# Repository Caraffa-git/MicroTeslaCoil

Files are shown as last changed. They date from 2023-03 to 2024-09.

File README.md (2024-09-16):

# μTeslaCoil
Small PCB for push-pull tesla coil with 50V boost converter

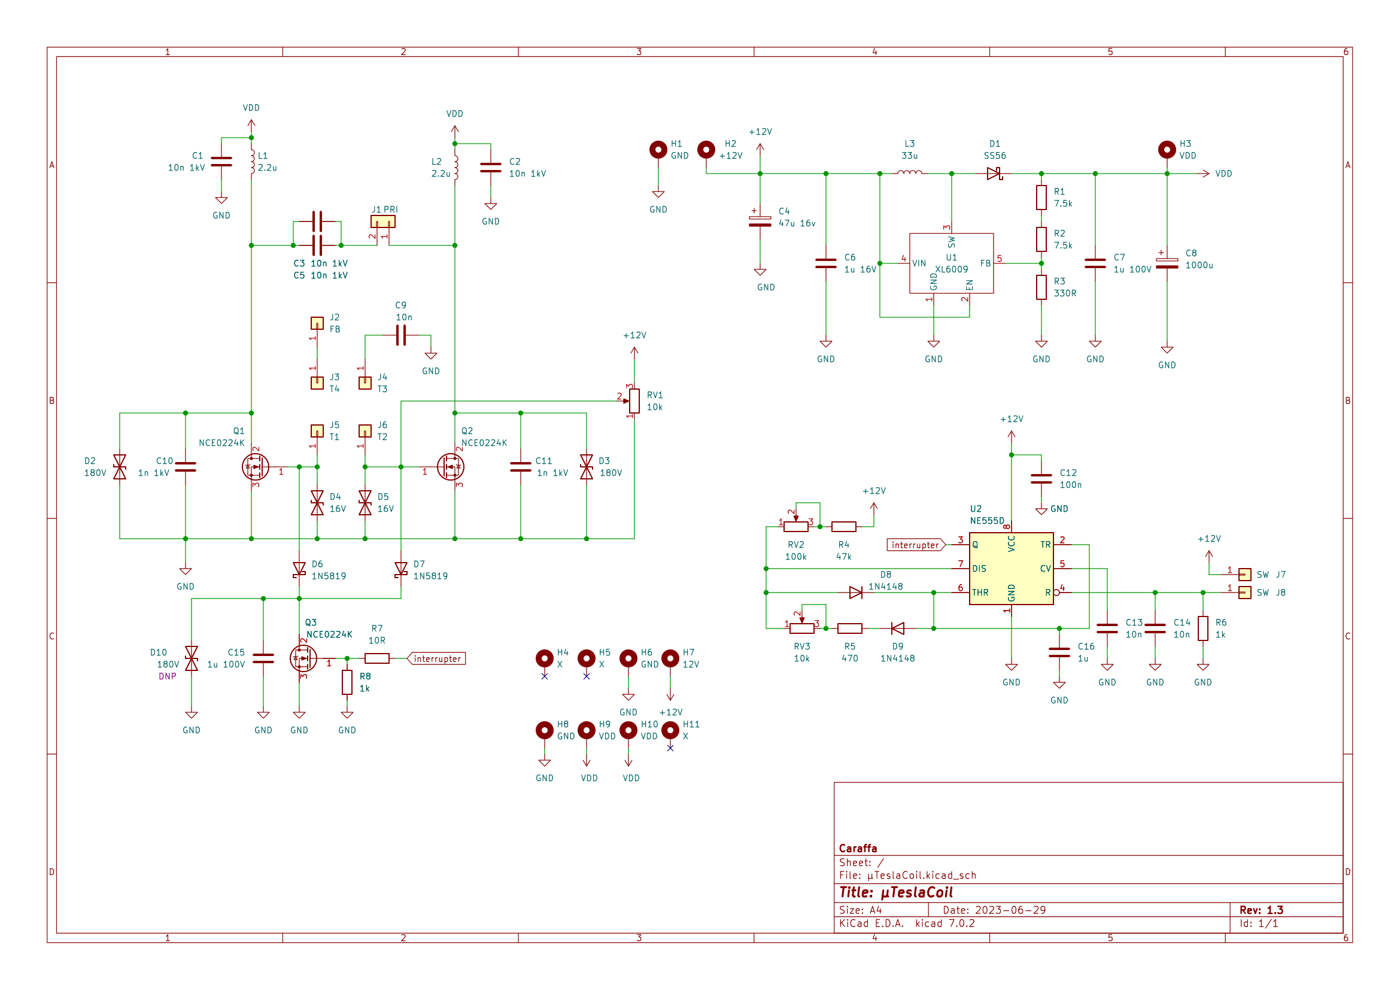
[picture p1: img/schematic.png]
schematic


## Notes and test results (<a href="https://github.com/Caraffa-git/MicroTeslaCoil/tree/b3fdc67581c9563461222aec662bbb1328c567a8">b3fdc67</a>)
The coil works, but aside from some not-so-wise design decisions that I changed in the current version, I encountered a few problems.
- At first the idea was to use a slayer-exciter sized secondary but as it turned out driving a coil with a frequency close to 5MHz can be challenging in terms of tuning. I ended up using a slightly larger secondary with a resonance frequency close to 500-600kHz.
- The lack of TVS diodes cost me some IGBTs so I added them in this version. As it turns out, reverse connection of the primary winding causes high voltage spikes and thus damage to the circuit.
- The voltage converter that I used has a limit of ~60V on the output, but there is some headroom so you can experiment with higher voltages. I think the circuit should be able to withstand about 80V on the input.

<!-- |   |   |   |
|---|---|---|
| ![Photo 2](./img/PIC_2.jpg) |![Photo 3](./img/PIC_3.jpg) | ![Photo 4](./img/PIC_4.jpg)| -->

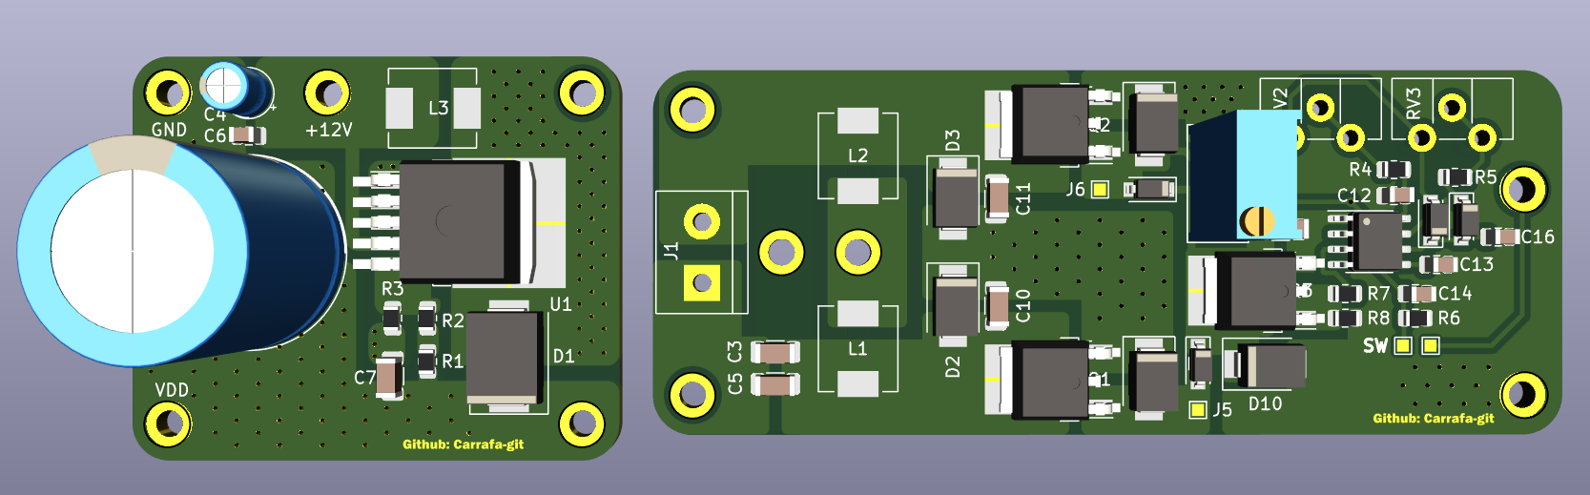
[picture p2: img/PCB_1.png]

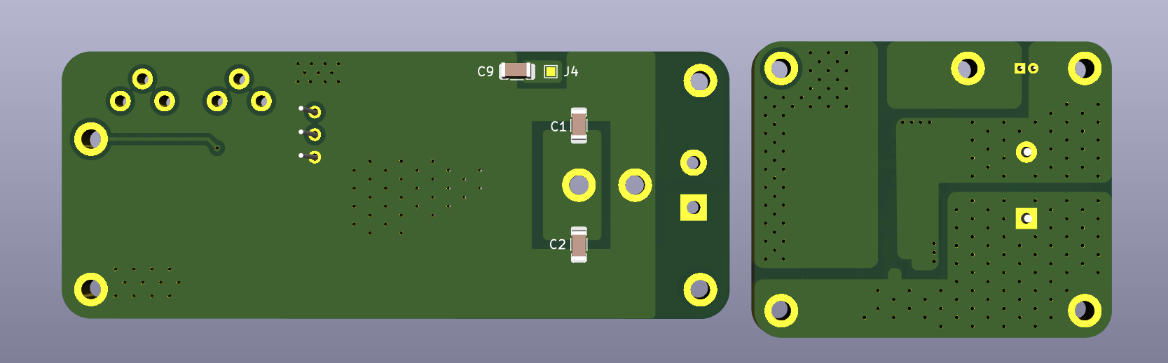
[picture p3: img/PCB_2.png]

<!-- ![base](./img/PIC_1.jpg) -->

## TODO
- Add Q3 gate protection
- Add U2 VCC regulation/protection 

## Links
https://www.youtube.com/watch?v=w9AY5RUtEMk   
https://tefatronix.g6.cz/display.php?page=sstc4&lang=en   
~~https://blog.naver.com/3happy3gong3/222702706706~~   
https://github.com/Caraffa-git/PCB-Art

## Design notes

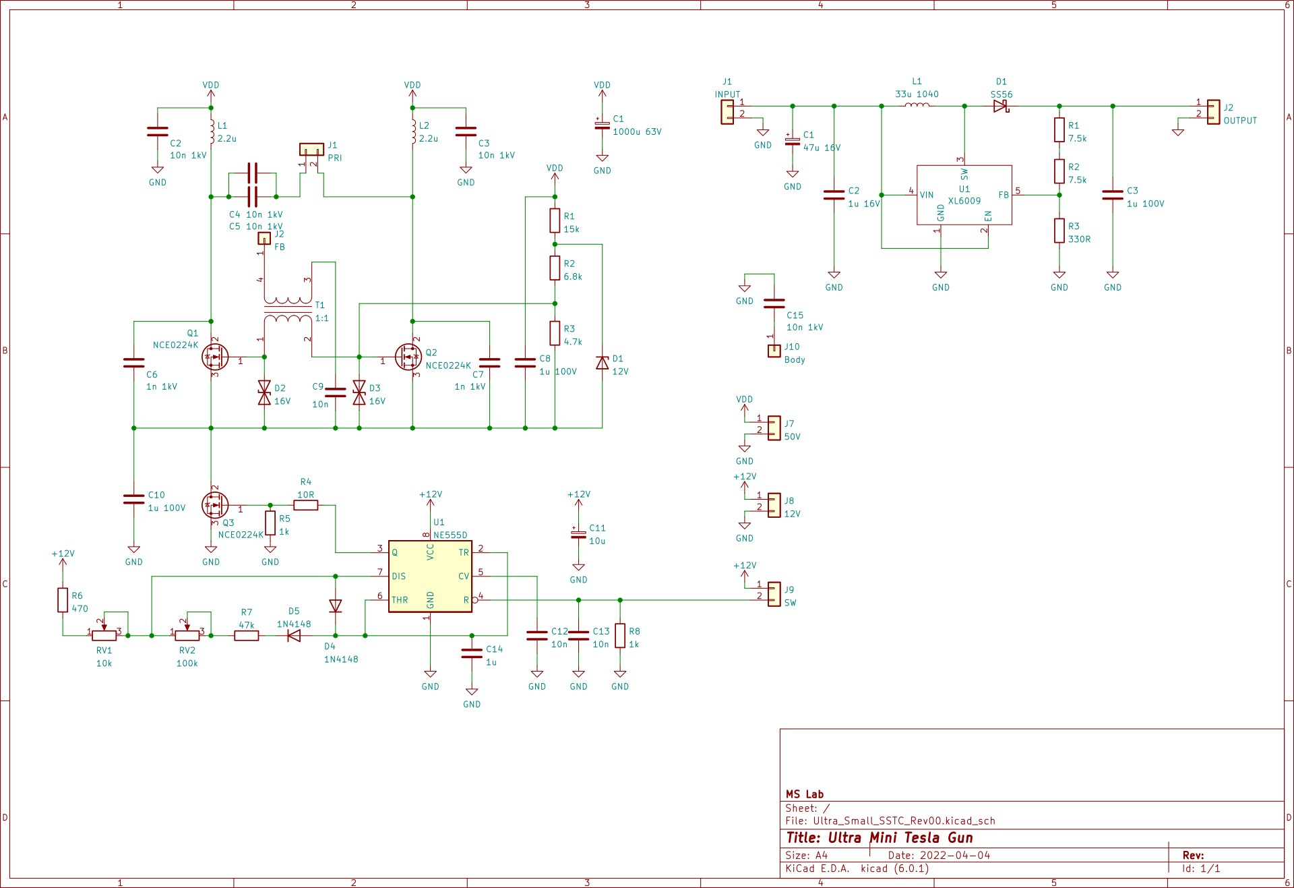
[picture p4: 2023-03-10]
img/original_schematic.png

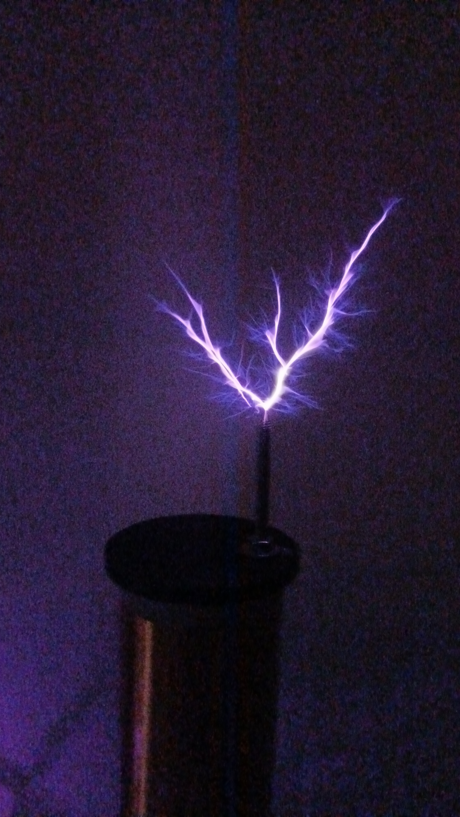
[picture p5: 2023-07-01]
img/PIC_3.jpg

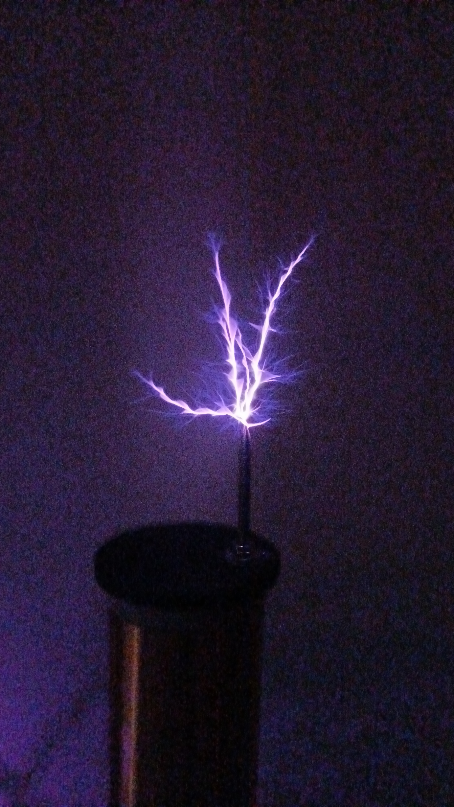
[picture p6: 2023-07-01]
img/PIC_4.jpg

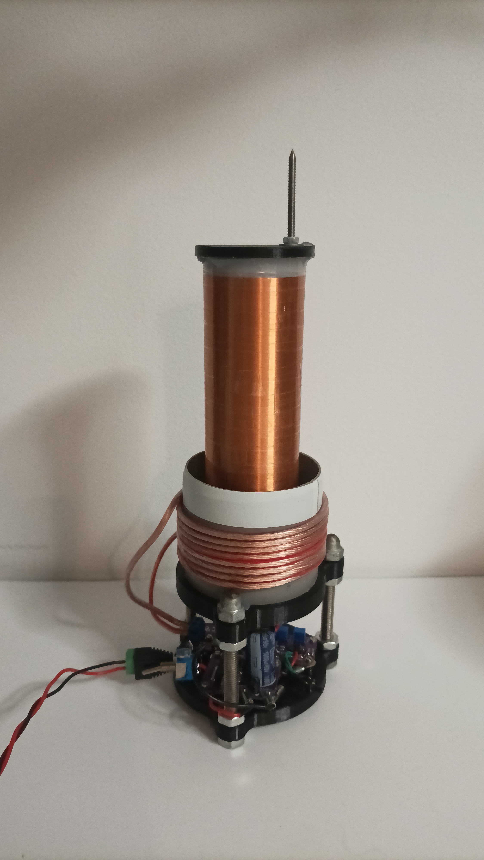
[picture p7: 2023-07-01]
img/PIC_2.jpg

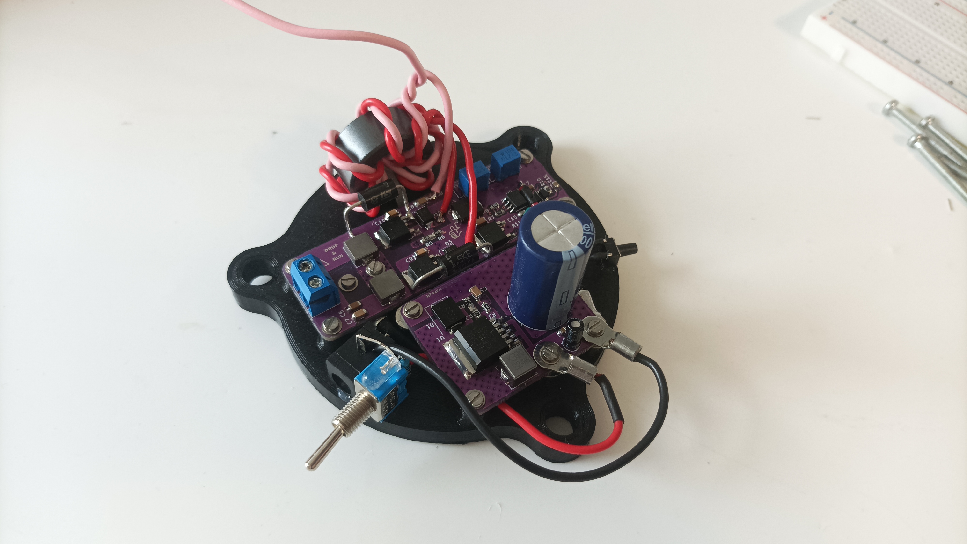
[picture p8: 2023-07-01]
img/PIC_1.jpg

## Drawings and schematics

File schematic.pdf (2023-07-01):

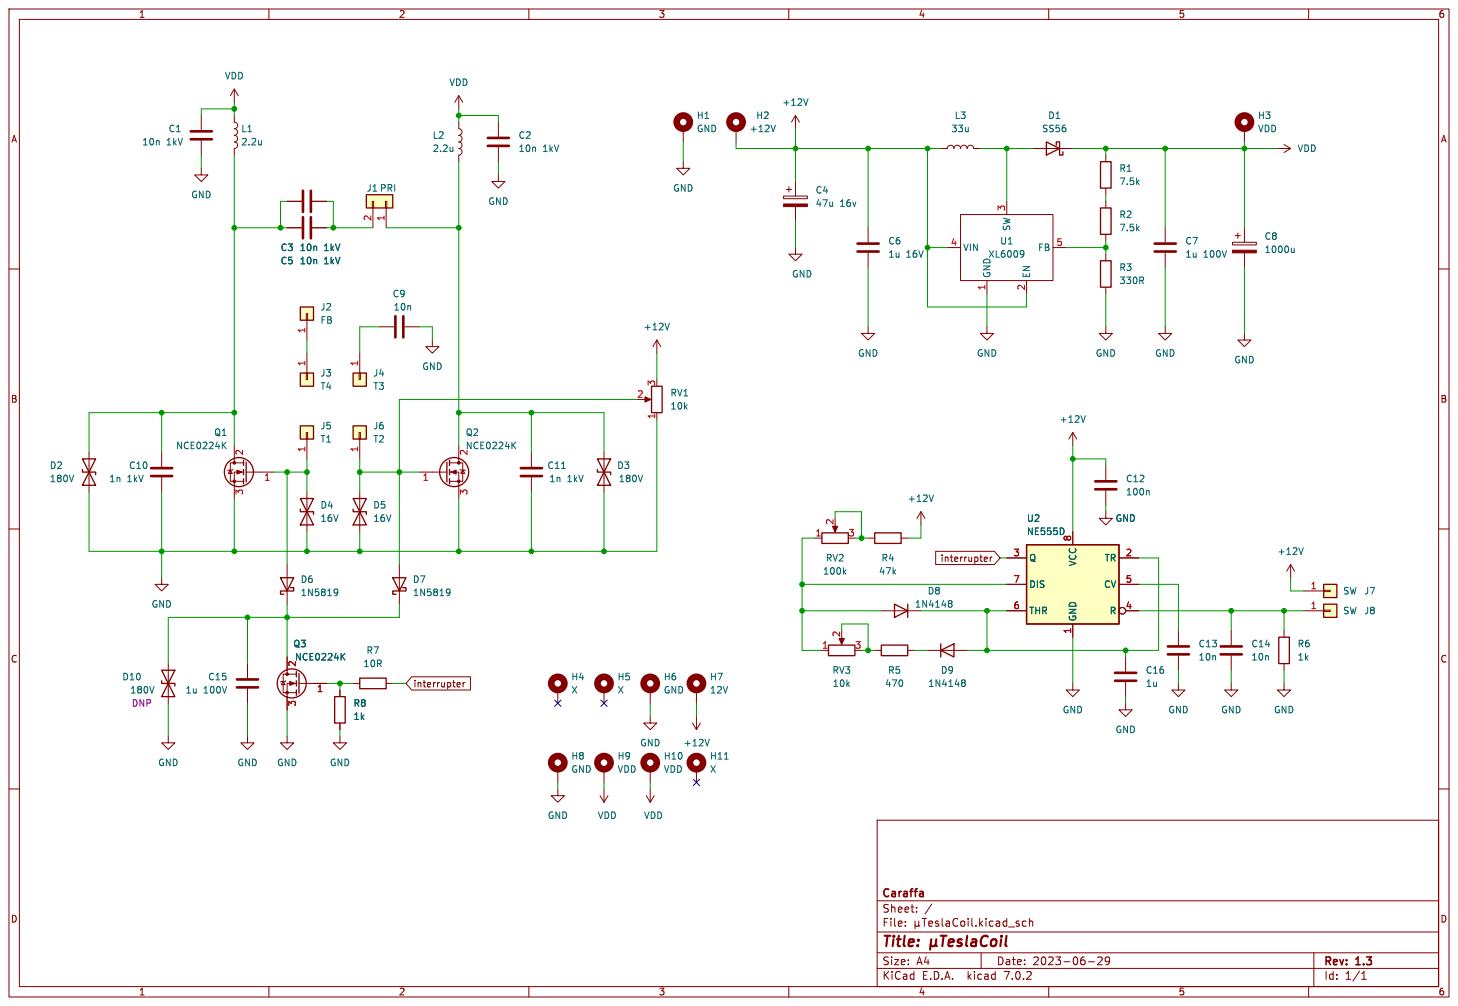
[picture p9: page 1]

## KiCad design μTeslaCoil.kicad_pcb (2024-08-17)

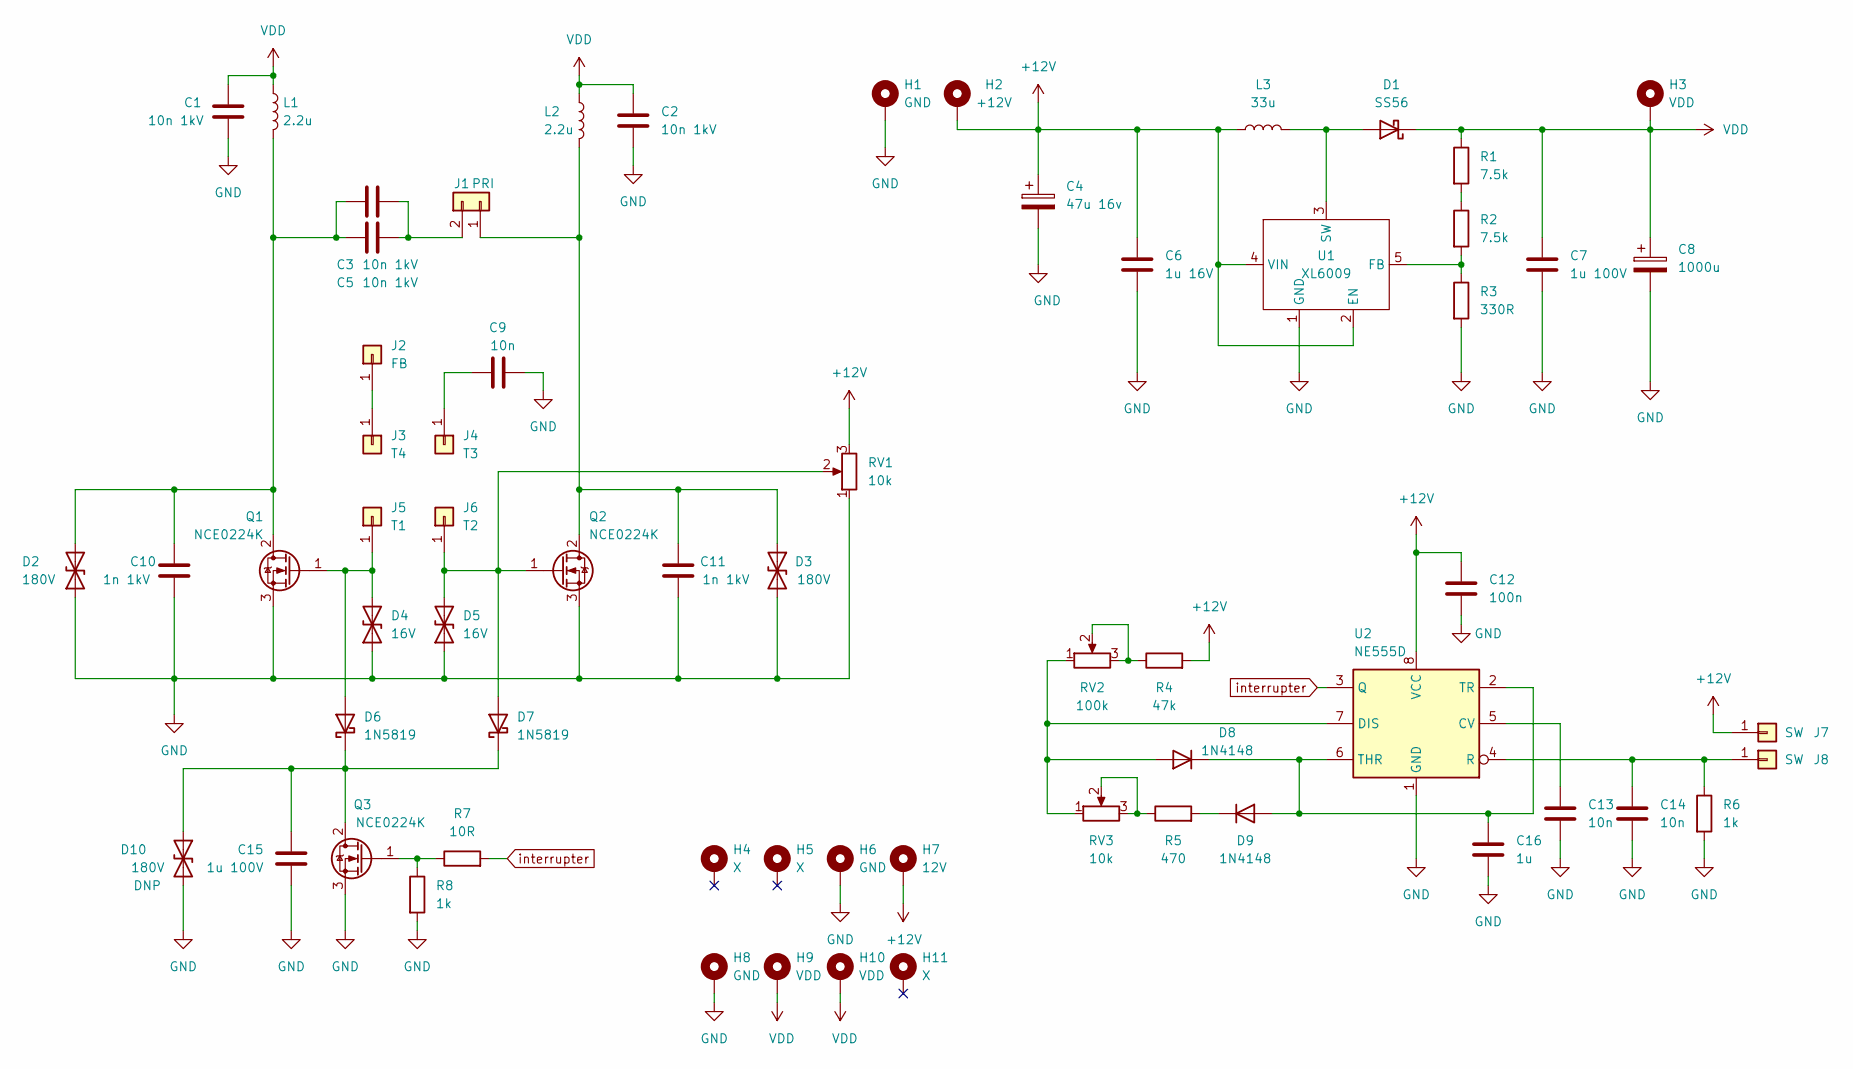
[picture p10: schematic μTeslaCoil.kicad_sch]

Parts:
C1, C2, C3, C5: 10n 1kV; C_1206_3216Metric
C4: 47u 16v; CP_Radial_D4.0mm_P1.50mm
C6: 1u 16V; C_0805_2012Metric
C7, C15: 1u 100V; C_1206_3216Metric
C8: 1000u; CP_Radial_D16.0mm_P7.50mm
C9: 10n; C_1206_3216Metric
C10, C11: 1n 1kV; C_1206_3216Metric
C12: 100n; C_0805_2012Metric
C13, C14: 10n; C_0805_2012Metric
C16: 1u; C_0805_2012Metric
D1: SS56; D_SMC
D2, D3, D10: 180V; D_SMB
D4, D5: 16V; D_SMB
D6, D7: 1N5819; D_SOD-123
D8, D9: 1N4148; D_SOD-123
H1, H6, H8: GND; MountingHole_2.2mm_M2_DIN965_Pad
H2: +12V; MountingHole_2.2mm_M2_DIN965_Pad
H3, H9, H10: VDD; MountingHole_2.2mm_M2_DIN965_Pad
H4, H5, H11: X; MountingHole_2.2mm_M2_DIN965_Pad
H7: 12V; MountingHole_2.2mm_M2_DIN965_Pad
J1: PRI; TerminalBlock_bornier-2_P5.08mm
J2: FB
J3: T4
J4: T3; TestPoint_Pad_1.0x1.0mm
J5: T1; TestPoint_Pad_1.0x1.0mm
J6: T2; TestPoint_Pad_1.0x1.0mm
J7, J8: SW; TestPoint_Pad_1.0x1.0mm
L1, L2: 2.2u; L 6.6x7.1
L3: 33u; L 6.6x7.3
Q1, Q2, Q3: NCE0224K; TO-252-2
R1, R2: 7.5k; R_0805_2012Metric
R3: 330R; R_0805_2012Metric
R4: 47k; R_0805_2012Metric
R5: 470; R_0805_2012Metric
R6, R8: 1k; R_0805_2012Metric
R7: 10R; R_0805_2012Metric
RV1: 10k; Potentiometer_Bourns_3296W_Vertical
RV2: 100k; Potentiometer_ACP_CA9-H2,5_Horizontal
RV3: 10k; Potentiometer_ACP_CA9-H2,5_Horizontal
U1: XL6009; TO-263-5_TabPin3
U2: NE555D; SOIC-8_3.9x4.9mm_P1.27mm

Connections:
+12V: C4.1, C6.1, C12.1, H2.1, H7.1, J7.1, L3.1, R4.2, RV1.3, U1.2 (EN), U1.4 (VIN), U2.8 (VCC)
GND: C1.2, C2.2, C4.2, C6.2, C7.2, C8.2, C9.2, C10.2, C11.2, C12.2, C13.2, C14.2, C15.2, C16.2, D2.1 (A1), D3.2 (A2), D4.1 (A1), D5.1 (A1), D10.2 (A2), H1.1, H6.1, H8.1, Q1.3 (S), Q2.3 (S), Q3.3 (S), R3.2, R6.2, R8.2, RV1.1, U1.1 (GND), U2.1 (GND)
unnamed: C3.2, C5.2, J1.2
unnamed: C9.1, J4.1
unnamed: C3.1, C5.1, C10.1, D2.2 (A2), L1.2, Q1.2 (D)
unnamed: C11.1, D3.1 (A1), J1.1, L2.2, Q2.2 (D)
unnamed: C13.1, U2.5 (CV)
unnamed: C14.1, J8.1, R6.1, U2.4 (R)
unnamed: C15.1, D6.1 (K), D7.1 (K), D10.1 (A1), Q3.2 (D)
unnamed: C16.1, D8.1 (K), D9.2 (A), U2.2 (TR), U2.6 (THR)
unnamed: D1.2 (A), L3.2, U1.3 (SW)
unnamed: D4.2 (A2), D6.2 (A), J5.1, Q1.1 (G)
unnamed: D5.2 (A2), D7.2 (A), J6.1, Q2.1 (G), RV1.2
unnamed: D8.2 (A), RV2.1, RV3.1, U2.7 (DIS)
unnamed: D9.1 (K), R5.2
unnamed: J2.1, J3.1
unnamed: Q3.1 (G), R7.1, R8.1
unnamed: R1.2, R2.1
unnamed: R2.2, R3.1, U1.5 (FB)
unnamed: R4.1, RV2.2, RV2.3
unnamed: R5.1, RV3.2, RV3.3
VDD: C1.1, C2.1, C7.1, C8.1, D1.1 (K), H3.1, H9.1, H10.1, L1.1, L2.1, R1.1
interrupter: R7.2, U2.3 (Q)

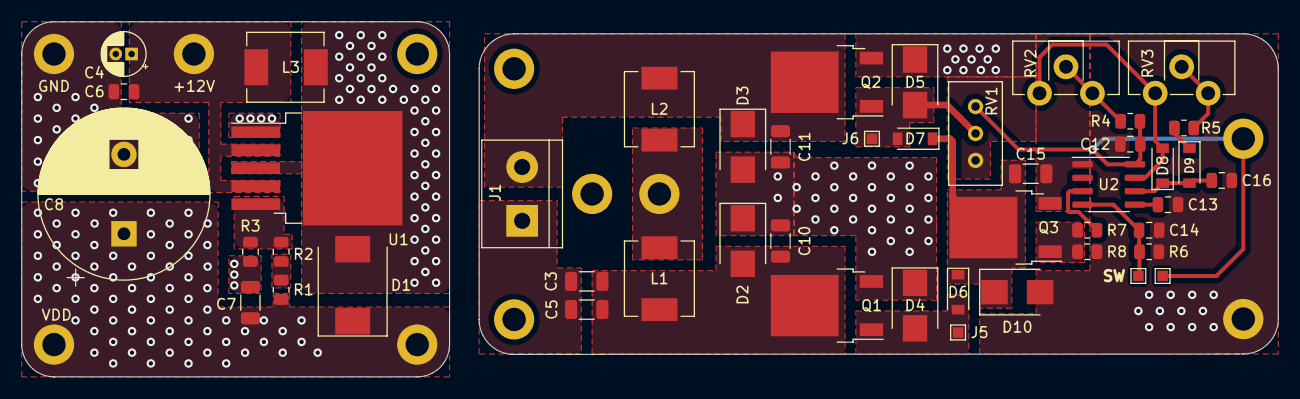
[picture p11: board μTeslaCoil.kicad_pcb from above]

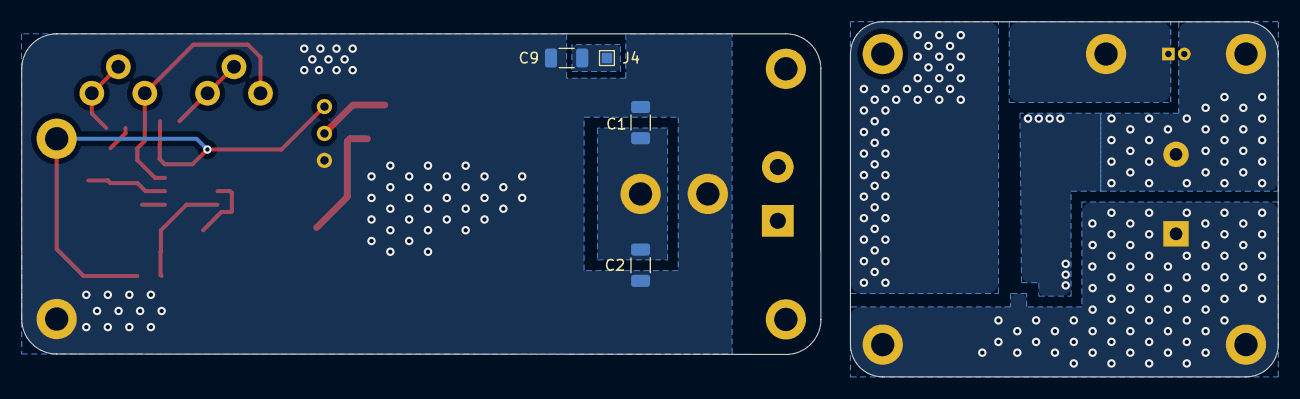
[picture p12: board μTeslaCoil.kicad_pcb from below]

Board: 2 copper layers, 118.6 x 33.5 mm, 62 parts (4 on the bottom side), 22 nets.

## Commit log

2023-02-18 small clean-up
    [μTeslaCoil.kicad_pcb]
2023-07-01 updated PCB view
2023-07-01 schematic update
2023-07-01 rev 1.3
    [μTeslaCoil.kicad_pcb, μTeslaCoil.kicad_sch]
2023-07-01 updated schematic
2023-07-01 updated BOM
2024-08-17 final clean-up
    [μTeslaCoil.kicad_pcb]
